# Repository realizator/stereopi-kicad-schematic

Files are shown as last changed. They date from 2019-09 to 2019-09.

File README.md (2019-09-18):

# StereoPi

This repo contains StereoPi schematics in KiCad. 
Originally, all schematics have been created in Altium, and now we're in the process of porting them to KiCad.

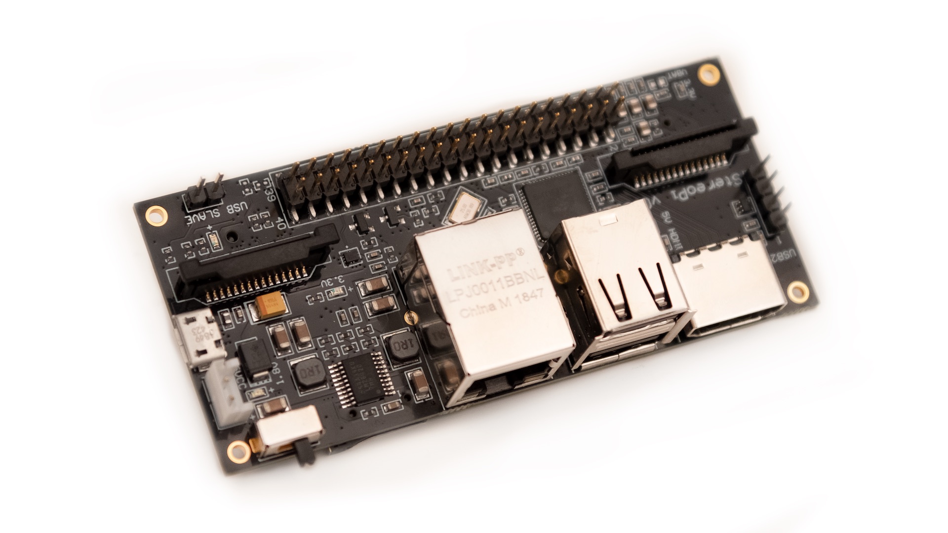
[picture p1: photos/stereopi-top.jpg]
StereoPi top photo


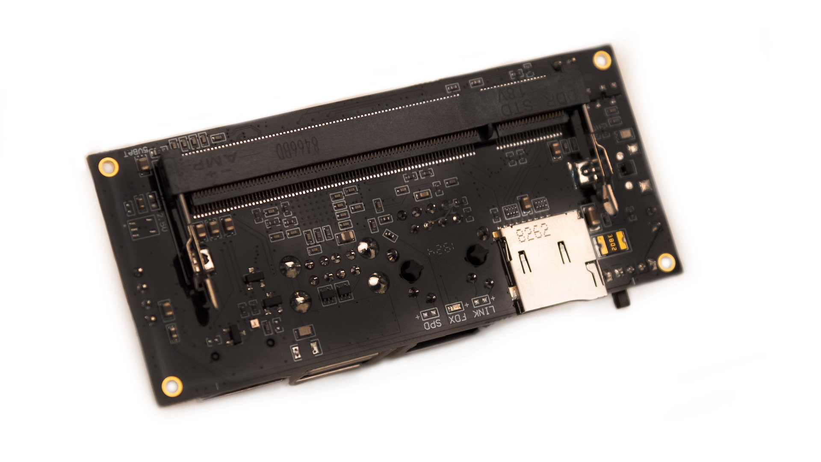
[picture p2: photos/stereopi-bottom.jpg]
StereoPi bottom photo


### Project site: 

http://stereopi.com

### Project Wiki:

https://wiki.stereopi.com

### Project forum:

https://forum.stereopi.com

**Special thanks to Twitter user @Knochi**

This man has achieved the gargantuan feat of drawing the first edition of our KiCad schematic from scratch!

Yes, this project is **Open Source**, and has been succesfully crowdfunded here:
https://www.crowdsupply.com/virt2real/stereopi

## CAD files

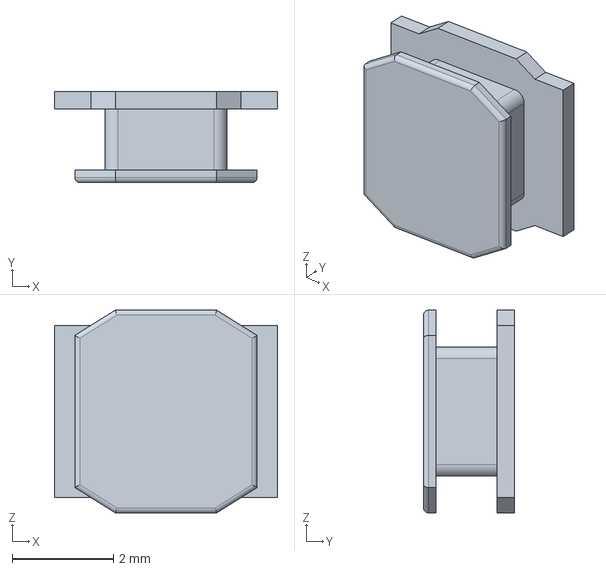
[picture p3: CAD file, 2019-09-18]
Datasheets/srn4018.stp
4.40 x 1.80 x 4.00 mm

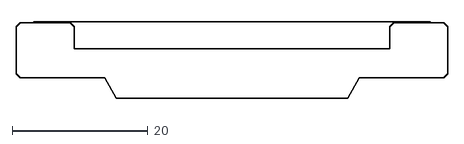
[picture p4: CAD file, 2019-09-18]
Datasheets/OutlineFPC.dxf
63.5 x 11.2

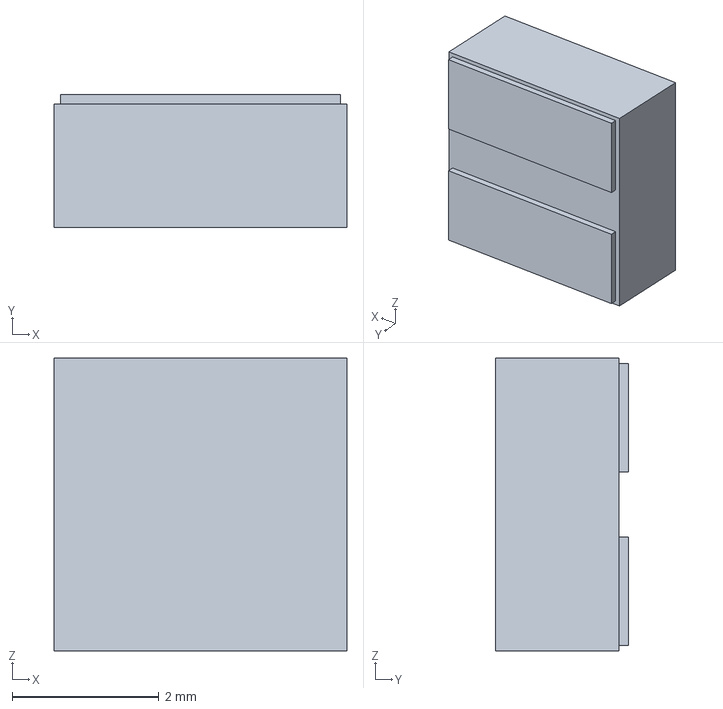
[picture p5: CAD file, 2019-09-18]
Datasheets/SRN4018TA.stp
3.99 x 1.80 x 3.99 mm

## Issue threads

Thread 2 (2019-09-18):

add Voltage requirements on C44 and C53

Knochi, 2019-09-18:
For separating capacitors between the grounds GND and GND_Sheild it will be great to mention their voltages on the schematic. This will help to understand, that this is a special capacitors, but not usual. I mean С44 and С53.

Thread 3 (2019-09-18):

Where are missing power pins on LAN9513

Knochi, 2019-09-18:
The question. LAN9513 chip has 5 power ports VDD33IO, but there is only pin19 on the schematics. Are there any other pins, or they are missed?

Knochi, 2019-09-18:
To make the schematic more clean those pins are hidden "behind" pin19. So all those pins get connected.

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

Closed 2019-09-18.

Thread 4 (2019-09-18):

Put conductor requirements on the schematics

Knochi, 2019-09-18:
**САМ – interface.**
Signals САМ0_D0, CAM0_D0, CAM0_C and CAM1_D0, CAM1_D0, CAM1_C has differential resistance 100 Ohm.
Mistmatch along the length in each diffpair 5mil (0.127mm).
Mistmatch along the length in each diffpair in interface САМ0 is 100mil.
Mistmatch along the length in each diffpair  in interfaceСАМ1 is 100mil.

**HDMI – interface**
Signals HDMI_D[2..0], HDMI_CLK has differential resistance of 100 Ohm.
Mistmatch along the length in each diffpair  is 5mil.
Data HDMI_D[2..0] equalized by length with respect to HDMI_CLK within 100mil.

**USB – interface**
USB-signals lines has  differential resistance 90 Ohm.
Mistmatch along the length in each diffpair is 5mil.
No need to equalize length of USB data between each other.

**Ethernet – interface LAN9513**
Tx and Rx signals differential resistance 100 Ohm.
Mistmatch along the length in each diffpair is 5mil.
No need to equalize length of Tx and Rx between each other.

Knochi, 2019-09-18:
Albeit the layout is already done, this maybe a good idea to help someone with their on layout version.
To find out how differential pair length matching is done in KiCAD see https://www.youtube.com/watch?v=chejn7dqpfQ

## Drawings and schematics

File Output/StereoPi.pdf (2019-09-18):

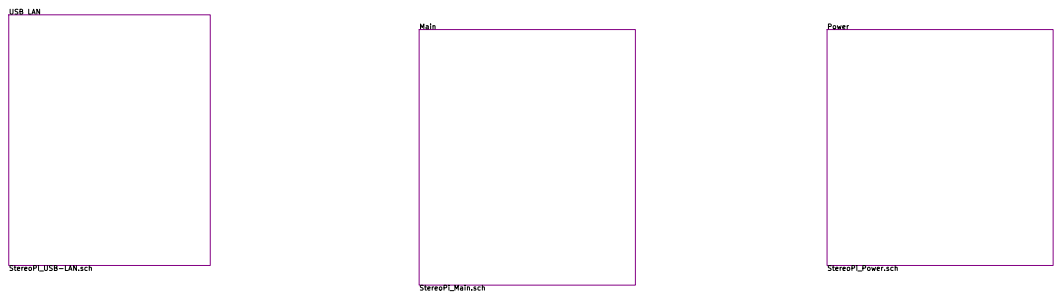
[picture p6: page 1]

Main StereoPi_Main.sch USB LAN

Id: 1/4 Title: File: StereoPi.sch Sheet: /

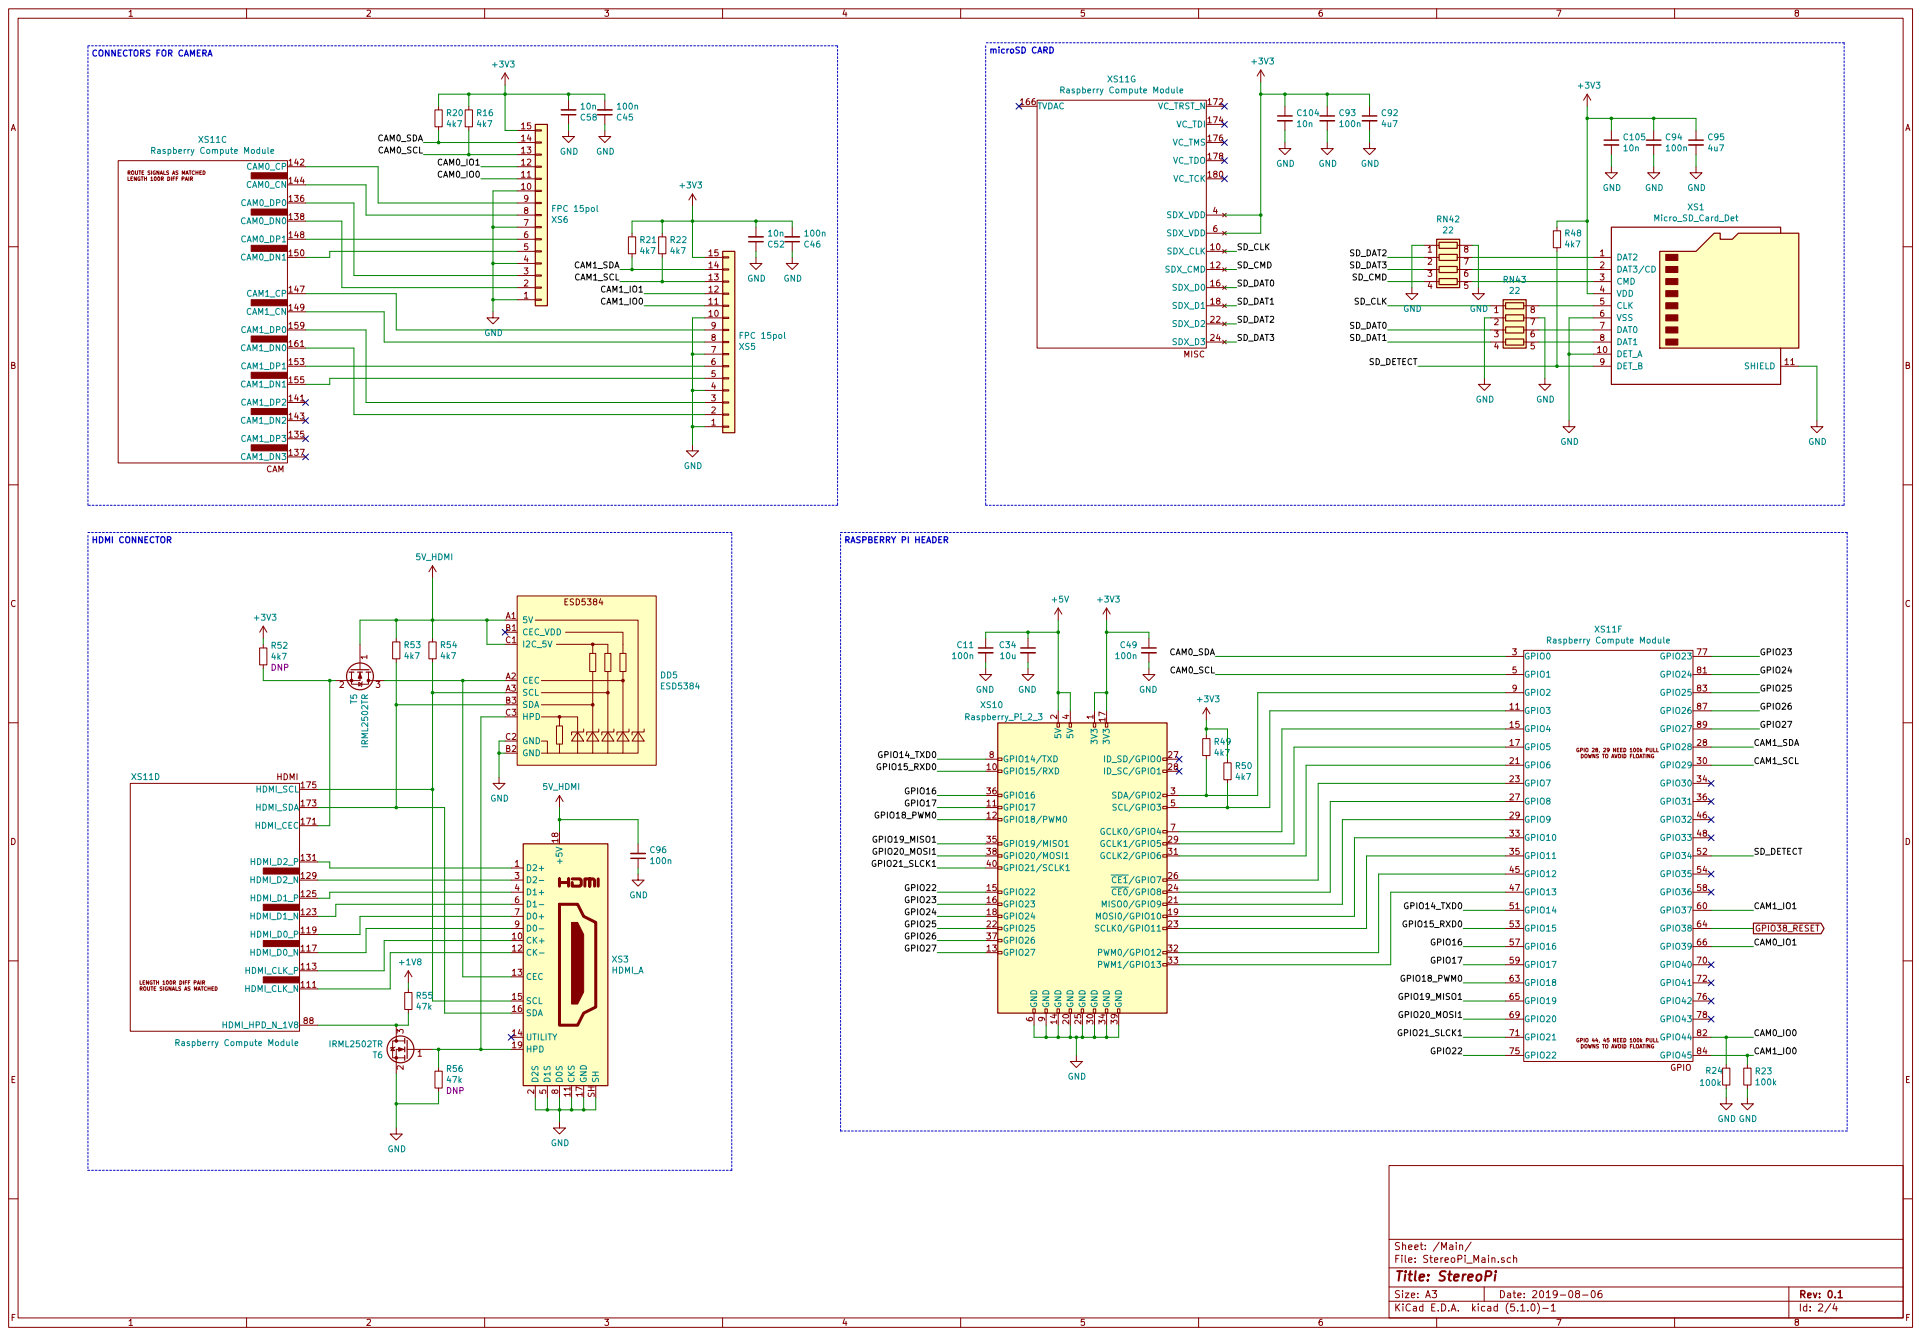
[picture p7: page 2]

89 XS11F Raspberry Compute Module CAM

9 XS10 Raspberry_Pi_2_3 D2+ 1 CK+ 10 CKS 11 CK- 12 CEC 13 UTILITY 14 SCL 15 SDA 16 GND 17 +5V 18 HPD 19 D2S

DOWNS TO AVOID FLOATING

File: StereoPi_Main.sch Sheet: /Main/
Id: 2/4 Title: StereoPi

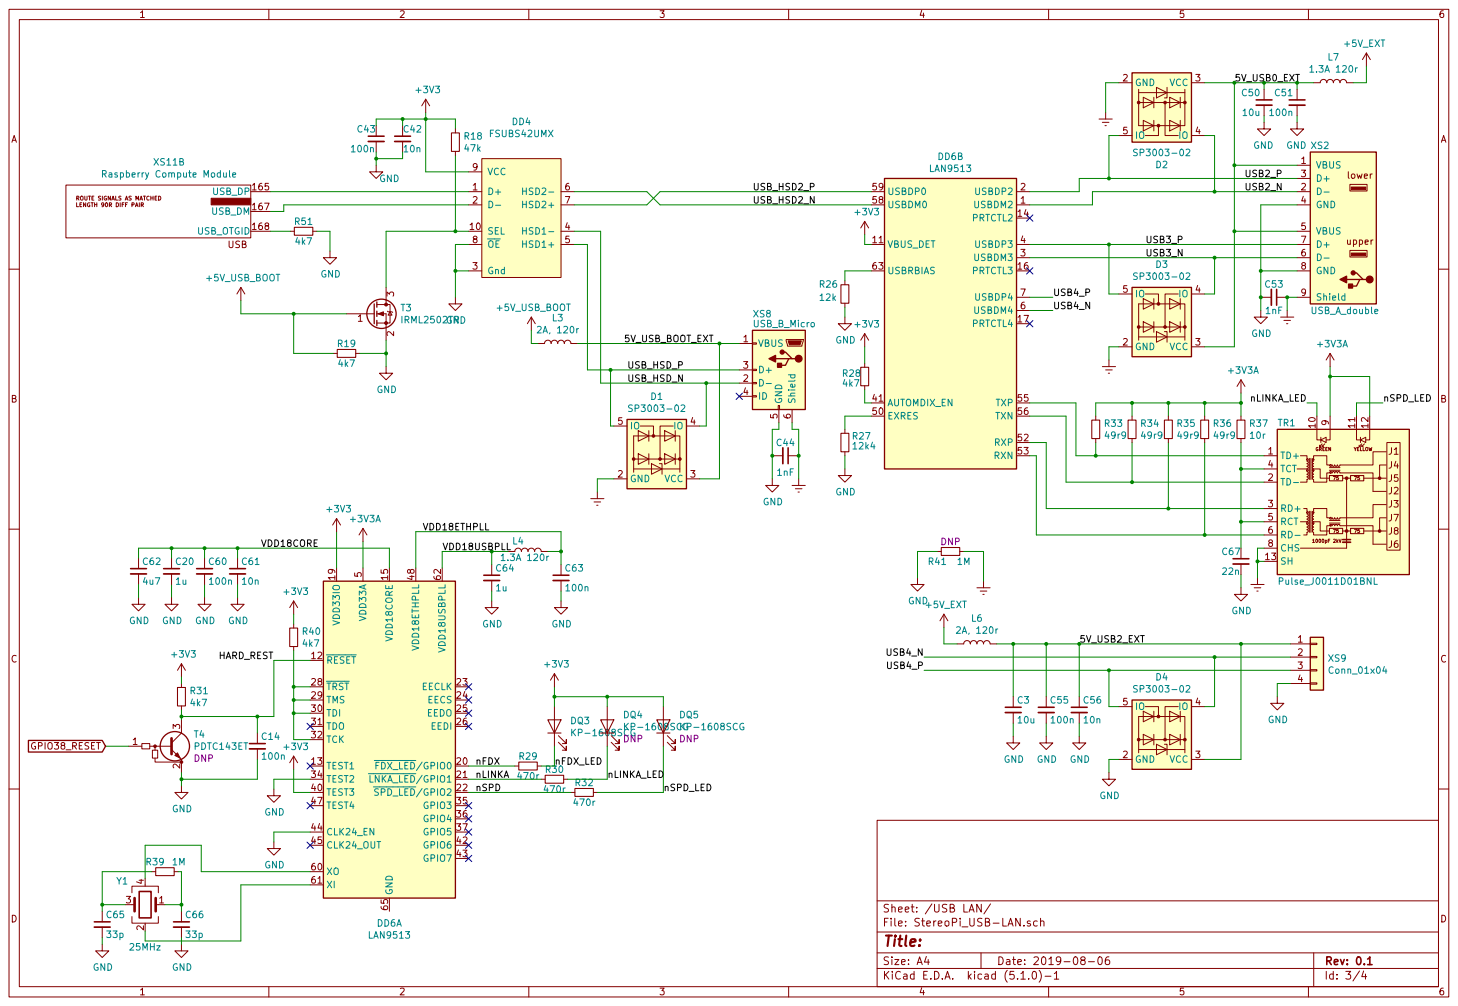
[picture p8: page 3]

VBUS 1 D- 2 D+ 3

USB_HSD_N

File: StereoPi_USB-LAN.sch Sheet: /USB LAN/
Id: 3/4 Title:

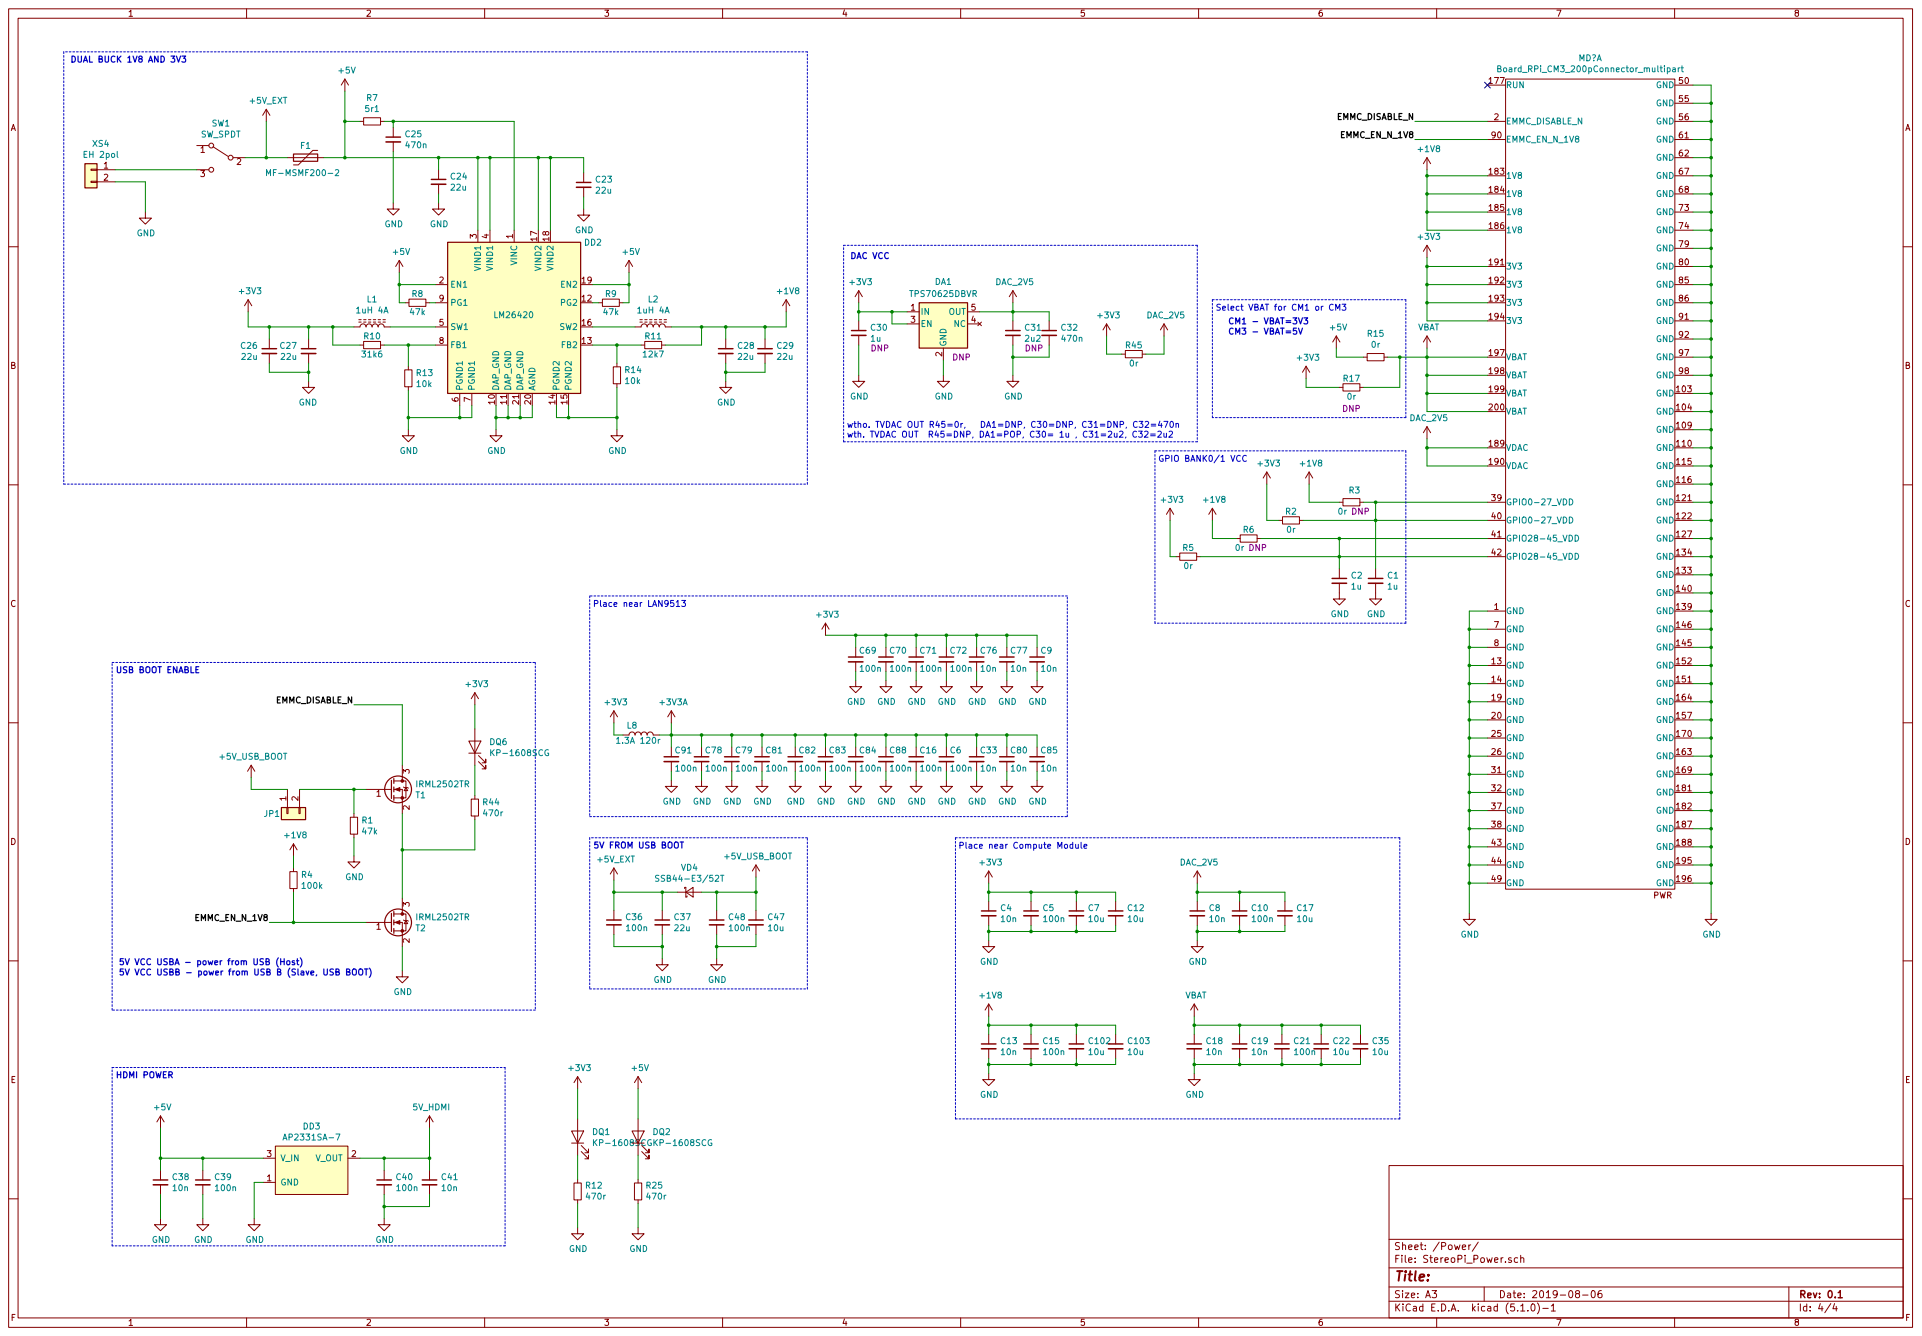
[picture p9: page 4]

10n GND GND GND GND GND GND GND

470r 5V VCC USBA - power from USB (Host)

5V VCC USBB - power from USB B (Slave, USB BOOT)

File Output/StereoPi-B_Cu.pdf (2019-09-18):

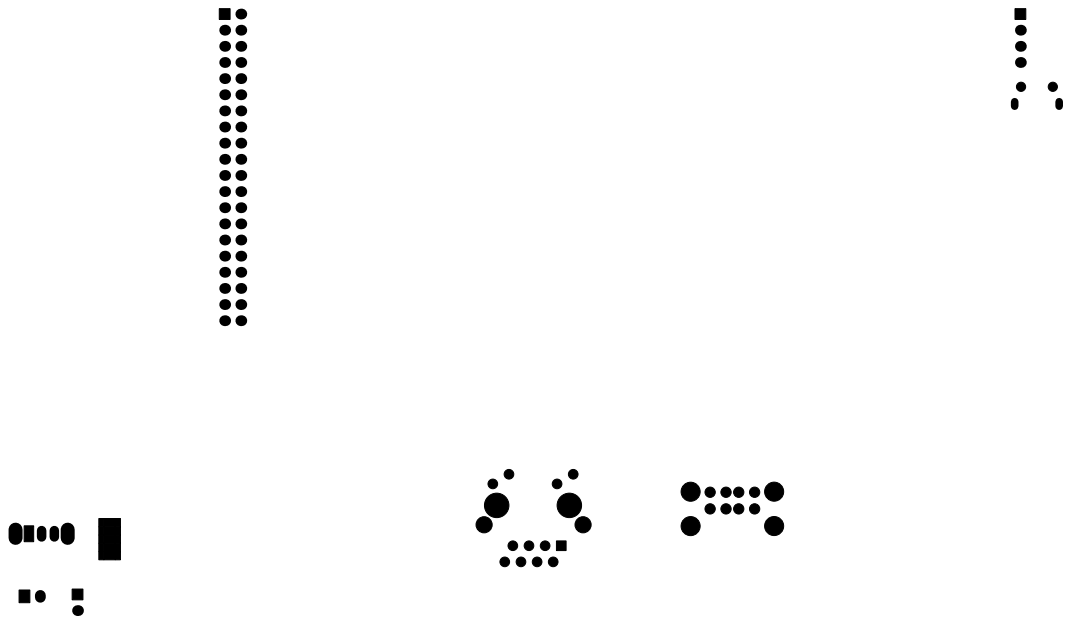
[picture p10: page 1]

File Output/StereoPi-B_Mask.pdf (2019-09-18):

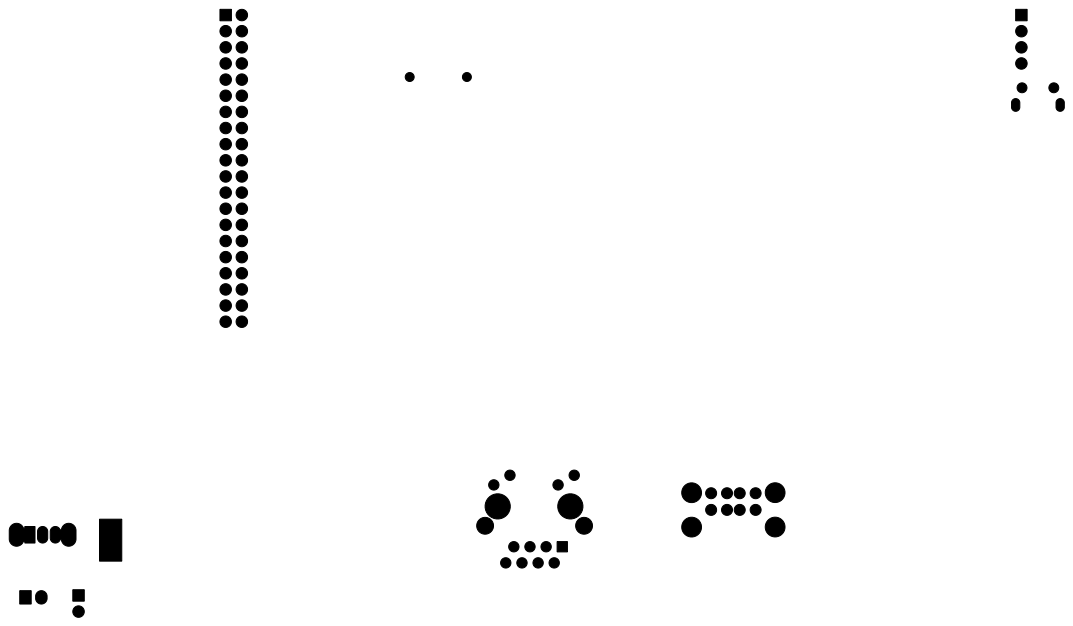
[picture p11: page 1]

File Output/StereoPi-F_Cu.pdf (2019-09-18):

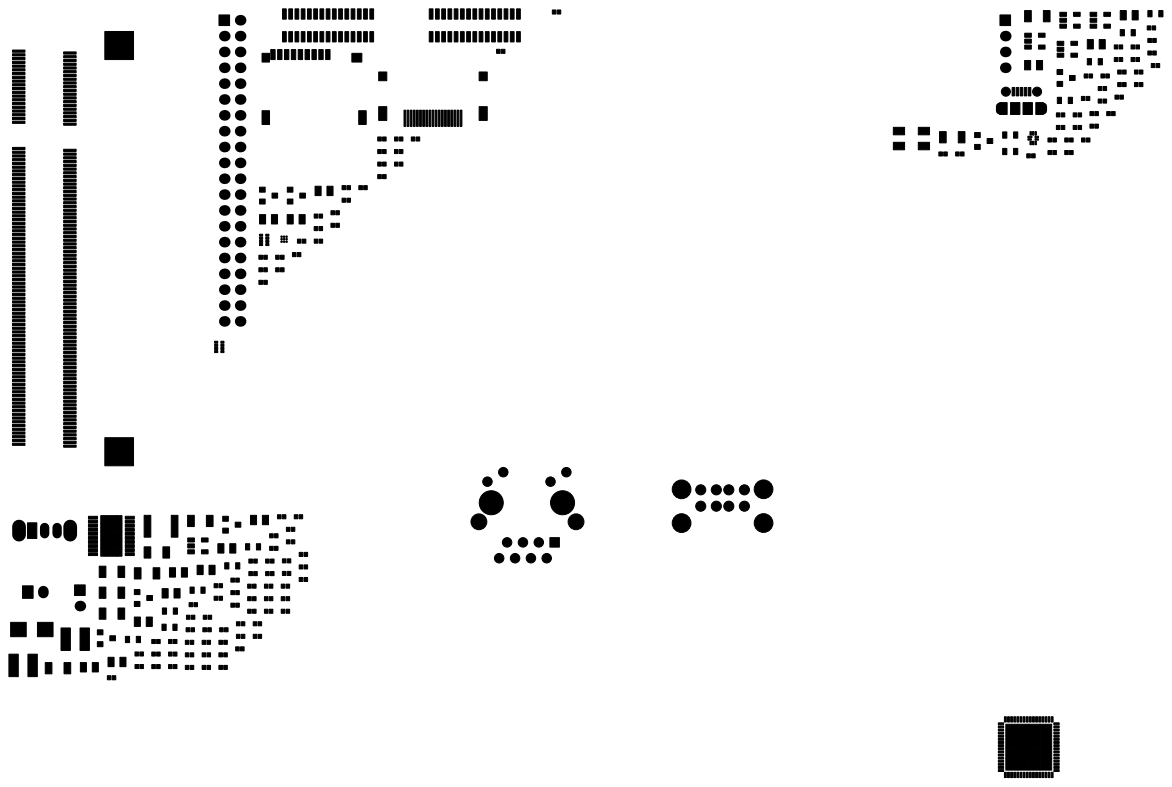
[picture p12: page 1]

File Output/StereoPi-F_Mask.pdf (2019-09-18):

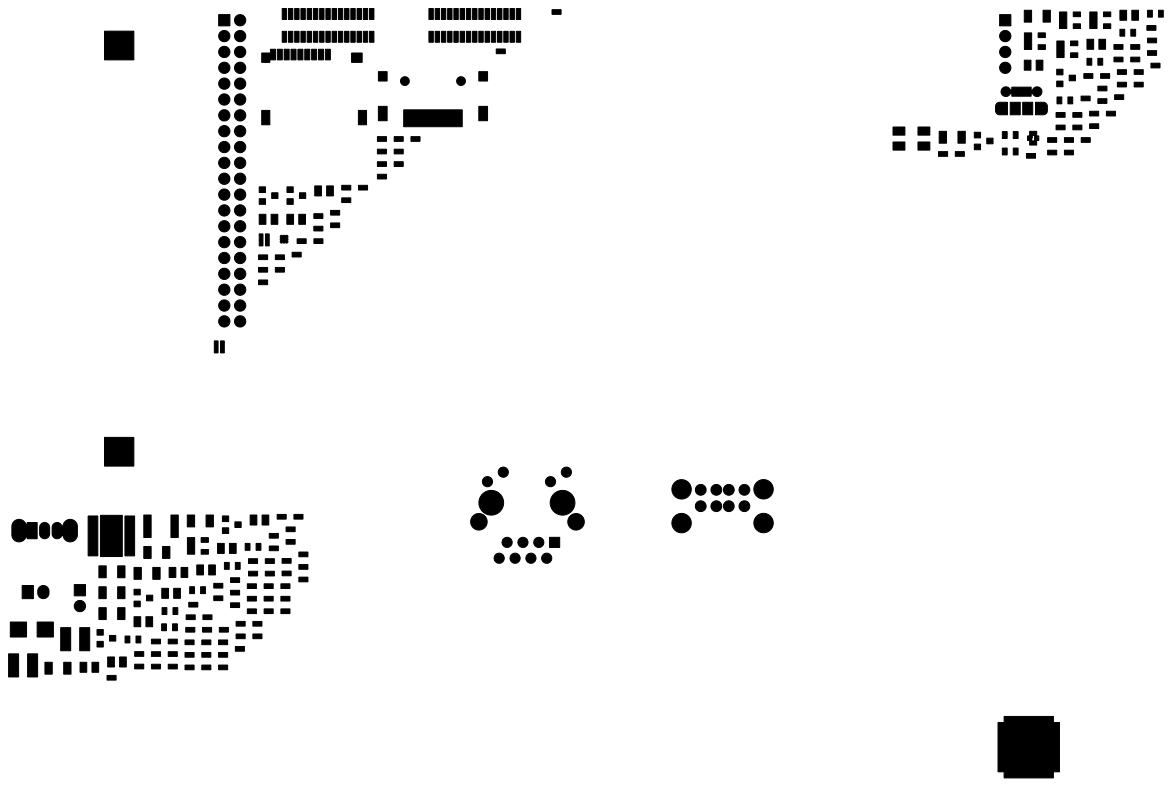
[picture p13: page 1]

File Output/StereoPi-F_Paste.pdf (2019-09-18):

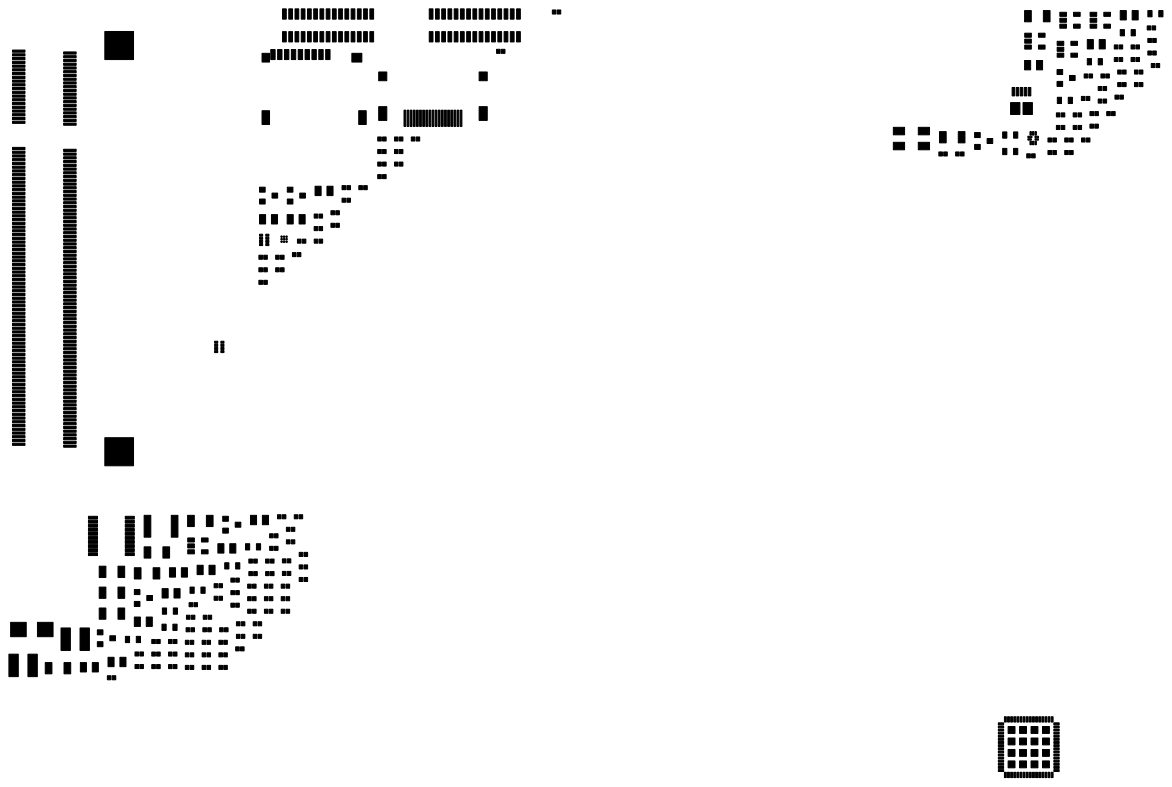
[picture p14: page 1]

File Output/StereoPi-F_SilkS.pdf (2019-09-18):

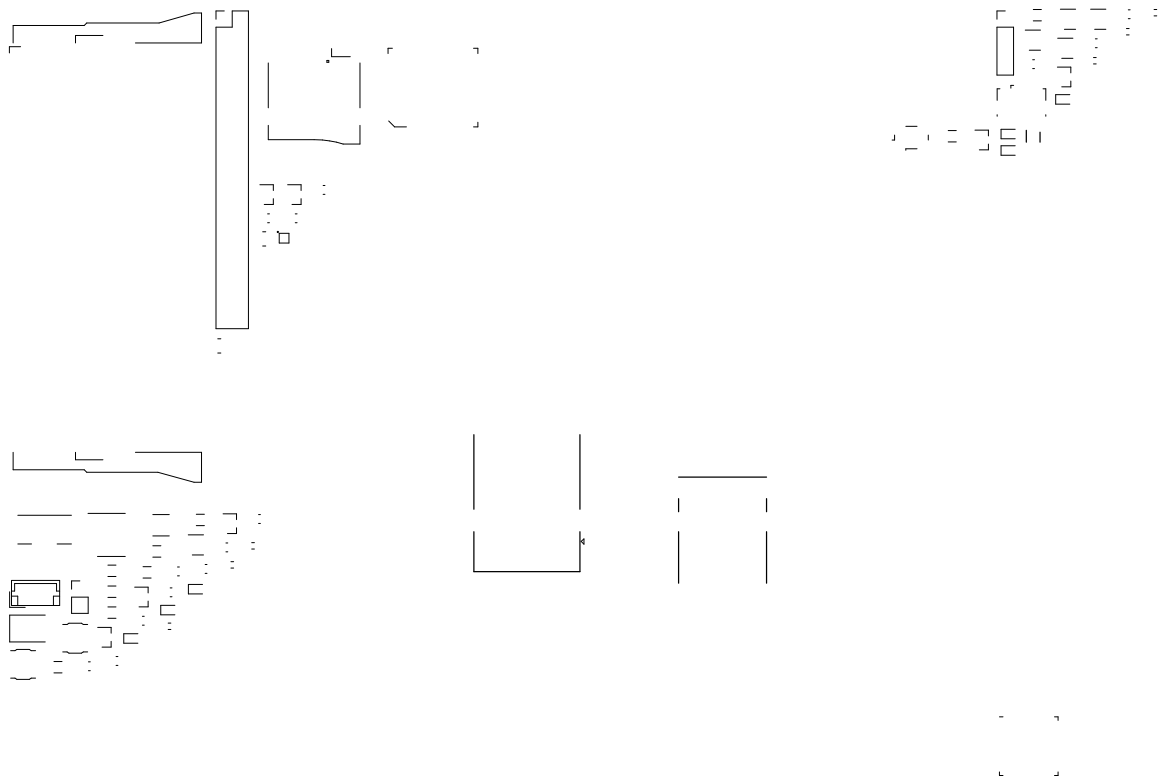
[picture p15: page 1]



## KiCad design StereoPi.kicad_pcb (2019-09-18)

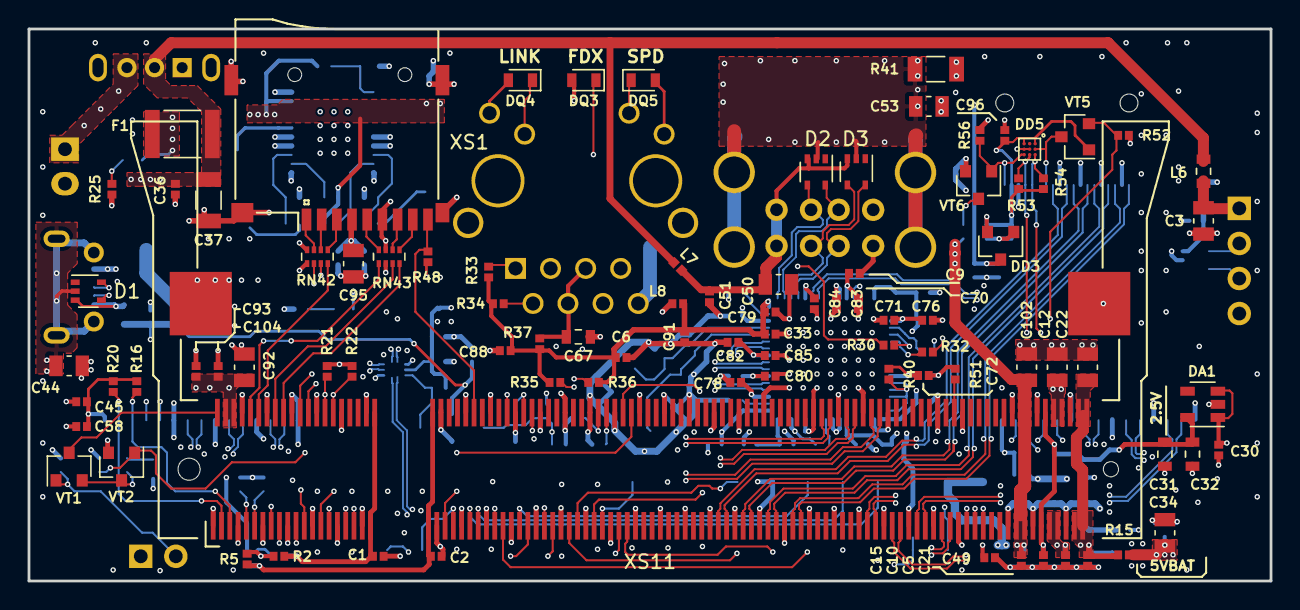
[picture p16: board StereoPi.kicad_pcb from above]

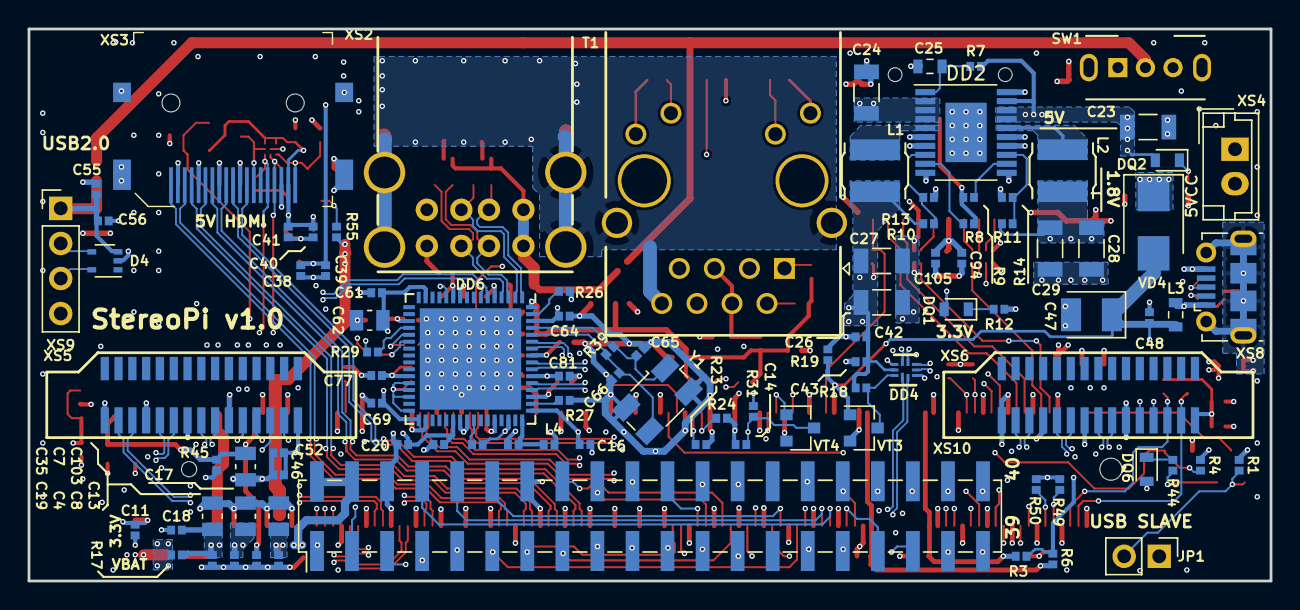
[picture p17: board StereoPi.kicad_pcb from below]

Board: 6 copper layers, 90.0 x 40.0 mm, 187 parts (98 on the bottom side), 141 nets.

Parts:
C1, C2, C20, C30, C64: 1u; C_0402_1005Metric
C3, C7, C12, C17, C22, C34, C35, C50, C102, C103: 10u; C_0805_2012Metric
C4, C8, C9, C13, C18, C19, C33, C38, C41, C42, C52, C56, C58, C61, C76, C77, C80, C85, C104, C105: 10n; C_0402_1005Metric
C5, C6, C10, C11, C14, C15, C16, C21, C36, C39, C40, C43, C45, C46, C48, C49, C51, C55, C60, C63, C69, C70, C71, C72, C78, C79, C81, C82, C83, C84, C88, C91, C93, C94, C96: 100n; C_0402_1005Metric
C23, C24, C26, C27, C28, C29, C37: 22u; C_1206_3216Metric
C25, C32: 470n; C_0603_1608Metric
C31: 2u2; C_0603_1608Metric
C44, C53: 1nF; C_0805_2012Metric
C47: 10u/10V; CP_EIA-3528-15_AVX-H
C62, C92, C95: 4u7; C_0805_2012Metric
C65, C66: 33p; C_0402_1005Metric
C67: 22n; C_0603_1608Metric
D1, D2, D3, D4: SP3003-02; SOT-353_SC-70-5
DA1: TPS70625; SOT-23-5
DD2: LM26420; HTSSOP-20-1EP_4.4x6.5mm_P0.65mm_ThermalPad_Ti
DD3: AP2331SA-7; SOT-23
DD4: FSUBS42UMX; UMLP-10_1.4x1.8x0.5mm_P0.4mm
DD5: ESD5384; WLCSP-9_1.14x1.14mm_P0.4mm
DD6: LAN9513; QFN-64-1EP_9x9mm_P0.5mm
DQ1, DQ2, DQ3, DQ4, DQ5, DQ6: KP-1608SCG; LED_0603_1608Metric
F1: MF-MSMF200-2; Fuse_1812_4532Metric
JP1: Conn_01x02; PinHeader_1x02_P2.54mm_Vertical
L1, L2: 1uH 4A; L_Bourns-SRN4018
L3, L6: 2A, 120r; L_0603_1608Metric
L4, L7, L8: 1.3A 120r; L_0402_1005Metric
R1, R8, R9, R18, R55, R56: 47k; R_0402_1005Metric
R2, R3, R5, R6, R15, R17, R45: 0r; R_0402_1005Metric
R4, R23, R24: 100k; R_0402_1005Metric
R7: 5r1; R_0402_1005Metric
R10: 31k6; R_0402_1005Metric
R11: 12k7; R_0402_1005Metric
R12, R25, R29, R30, R32, R44: 470r; R_0402_1005Metric
R13, R14: 10k; R_0402_1005Metric
R16, R19, R20, R21, R22, R28, R31, R40, R48, R49, R50, R51, R52, R53, R54: 4k7; R_0402_1005Metric
R26: 12k; R_0402_1005Metric
R27: 12k4; R_0402_1005Metric
R33, R34, R35, R36: 49r9; R_0402_1005Metric
R37: 10r; R_0402_1005Metric
R39: 1M; R_0402_1005Metric
R41: 1M; R_1206_3216Metric
RN42, RN43: 22; R_Array_Concave_4x0402
SW1: SW_SPDT; SK12D07VG3
T1: Pulse_J0011D01BNL; Conn_RJ45_Transformer_LEDs
VD4: SSB44; D_SMB
VT1, VT2, VT3, VT5, VT6: IRML2502TR; SOT-23
VT4: PDTC143ET; SOT-23
XS1: Micro_SD_Card_Det; Conn_uSDcard
XS2: USB_A_double; CON_USB-A_2-port
XS3: HDMI_A; HDMI_A_Female_2000-1-2-41-00-BK
XS4: EH 2pol; JST_EH_B02B-EH-A_1x02_P2.50mm_Vertical
XS5, XS6: FPC 15pol; FPC-15_VERTICAL_2
XS8: USB_B_Micro; USB_Micro-B_Molex-105017-0001
XS9: Conn_01x04; PinHeader_1x04_P2.54mm_Vertical
XS10: Raspberry_Pi_2_3; PinHeader_2x20_P2.54mm_Vertical_SMD
XS11: S0DIMM DDR2 Standard; Conn_TE-DDR2-SODIMM-0.6-200P-doublesided
Y1: 25MHz; Crystal_SMD_Abracon_ABM3B-4Pin_5.0x3.2mm

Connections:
1V8: C13.1, C15.1, C28.1, C29.1, C102.1, C103.1, L2.2, R3.2, R4.1, R6.2, R11.1, R55.1, XS11.183, XS11.184, XS11.185, XS11.186
3V3: C4.1, C5.1, C7.1, C9.1, C12.1, C26.1, C27.1, C30.1, C42.1, C43.1, C45.2, C46.2, C49.1, C52.2, C58.2, C69.1, C70.1, C71.1, C72.1, C76.1, C77.1, C92.1, C93.1, C94.1, C95.1, C104.1, C105.1, DA1.1, DA1.3, DD4.9, DD6.11, DD6.19, DD6.27, DD6.33, DD6.39, DD6.40, DD6.46, DQ1.2, DQ3.2, DQ4.2, DQ5.2, DQ6.2, L1.1, L8.1, R2.2, R5.2, R10.2, R16.1, R17.2, R18.1, R20.1, R21.1, R22.1, R28.1, R31.1, R40.1, R45.2, R48.2, R49.1, R50.1, R52.1, T1.9, T1.12, XS1.4, XS5.15, XS6.15, XS10.1, XS10.17, XS11.4, XS11.6, XS11.191, XS11.192, XS11.193, XS11.194
5VCC: C11.1, C23.1, C24.1, C34.1, C38.1, C39.1, DD2.2, DD2.3, DD2.4, DD2.17, DD2.18, DD2.19, DD3.3, DQ2.2, F1.1, R7.2, R8.2, R9.2, R15.2, XS10.2, XS10.4
5VCC_EXT: C36.1, C37.1, F1.2, L6.1, L7.1, SW1.2, VD4.1
5VCC_HDMI: C40.1, C41.1, C96.2, DD3.2, DD5.A1, DD5.C1, R53.1, R54.1, VT5.1, XS3.18
5V_EXT: SW1.3, XS4.1
+1V8_CORE: C20.1, C60.1, C61.1, C62.1, DD6.15, DD6.38
+1V8_ETH: C63.1, DD6.48, L4.2
+3V3A: C6.1, C16.1, C33.1, C78.1, C79.1, C80.1, C81.1, C82.1, C83.1, C84.1, C85.1, C88.1, C91.1, DD6.5, DD6.10, DD6.49, DD6.51, DD6.54, DD6.57, DD6.64, L8.2, R33.1, R34.1, R35.1, R36.1, R37.1
+5V_USB_BOOT: C47.1, C48.1, JP1.1, L3.1, R19.2, VD4.2, VT3.1
/Main/CAM0_IO0: R24.1, XS6.11, XS11.82
/Main/CAM0_IO1: XS6.12, XS11.66
/Main/CAM0_SCL: R16.2, XS6.13, XS11.5
/Main/CAM0_SDA: R20.2, XS6.14, XS11.3
/Main/CAM1_IO0: R23.1, XS5.11, XS11.84
/Main/CAM1_IO1: XS5.12, XS11.60
/Main/CAM1_SCL: R22.2, XS5.13, XS11.30
/Main/CAM1_SDA: R21.2, XS5.14, XS11.28
/Main/GPIO14_TXD0: XS10.8, XS11.51
/Main/GPIO15_RXD0: XS10.10, XS11.53
/Main/GPIO16: XS10.36, XS11.57
/Main/GPIO17: XS10.11, XS11.59
/Main/GPIO18_PWM0: XS10.12, XS11.63
/Main/GPIO19_MISO1: XS10.35, XS11.65
/Main/GPIO20_MOSI1: XS10.38, XS11.69
/Main/GPIO21_SLCK1: XS10.40, XS11.71
/Main/GPIO22: XS10.15, XS11.75
/Main/GPIO23: XS10.16, XS11.77
/Main/GPIO24: XS10.18, XS11.81
/Main/GPIO25: XS10.22, XS11.83
/Main/GPIO26: XS10.37, XS11.87
/Main/GPIO27: XS10.13, XS11.89
/Main/HDMI_CLK_N: XS3.12, XS11.111
/Main/HDMI_CLK_P: XS3.10, XS11.113
/Main/HDMI_D0_N: XS3.9, XS11.117
/Main/HDMI_D0_P: XS3.7, XS11.119
/Main/HDMI_D1_N: XS3.6, XS11.123
/Main/HDMI_D1_P: XS3.4, XS11.125
/Main/HDMI_D2_N: XS3.3, XS11.129
/Main/HDMI_D2_P: XS3.1, XS11.131
/Main/HDMI_SCL: DD5.A3, R54.2, XS3.15, XS11.175
/Main/HDMI_SDA: DD5.B3, R53.2, XS3.16, XS11.173
/Main/SD_CLK: RN43.1, XS11.10
/Main/SD_CMD: RN42.4, XS11.12
/Main/SD_DAT0: RN43.3, XS11.16
/Main/SD_DAT1: RN43.4, XS11.18
/Main/SD_DAT2: RN42.2, XS11.22
/Main/SD_DAT3: RN42.3, XS11.24
/Main/SD_DETECT: R48.1, XS1.9, XS11.52
/Power/1V8_SW: DD2.16, L2.1
/Power/3V3_SW: DD2.5, L1.2
/Power/EMMC_DISABLE_N: VT1.3, XS11.2
/Power/EMMC_EN_N_1V8: R4.2, VT2.1, XS11.90
/USB LAN/5V_USB0_EXT: C50.1, C51.1, D2.3, D3.3, L7.2, XS2.1, XS2.5
/USB LAN/5V_USB2_EXT: C3.1, C55.1, C56.1, D4.3, L6.2, XS9.1
/USB LAN/5V_USB_BOOT_EXT: D1.3, L3.2, XS8.1
/USB LAN/ETH_RX_N: DD6.53, R36.2, T1.6
/USB LAN/ETH_RX_P: DD6.52, R35.2, T1.3
/USB LAN/ETH_TX_N: DD6.56, R34.2, T1.2
/USB LAN/ETH_TX_P: DD6.55, R33.2, T1.1
/USB LAN/HARD_RESET: C14.1, DD6.12, R31.2, VT4.3
/USB LAN/USB2_N: D2.4, DD6.1, XS2.2
/USB LAN/USB2_P: D2.5, DD6.2, XS2.3
/USB LAN/USB3_N: D3.4, DD6.3, XS2.6
/USB LAN/USB3_P: D3.5, DD6.4, XS2.7
/USB LAN/USB4_N: D4.4, DD6.6, XS9.2
/USB LAN/USB4_P: D4.5, DD6.7, XS9.3
/USB LAN/USB_HSD2_N: DD4.6, DD6.58
/USB LAN/USB_HSD2_P: DD4.7, DD6.59
/USB LAN/USB_HSD_N: D1.4, DD4.4, XS8.2
/USB LAN/USB_HSD_P: D1.5, DD4.5, XS8.3
/USB LAN/VDD18USBPLL: C64.1, DD6.62, L4.1
/USB LAN/nFDX: DD6.20, R29.2
/USB LAN/nFDX_LED: DQ3.1, R29.1
/USB LAN/nLINKA: DD6.21, R30.2
/USB LAN/nLINKA_LED: DQ4.1, R30.1, T1.10
/USB LAN/nSPD: DD6.22, R32.2
/USB LAN/nSPD_LED: DQ5.1, R32.1, T1.11
DAC_2V5: C8.1, C10.1, C17.1, C31.1, C32.1, DA1.5, R45.1, XS11.189, XS11.190
GND: C1.2, C2.2, C3.2, C4.2, C5.2, C6.2, C7.2, C8.2, C9.2, C10.2, C11.2, C12.2, C13.2, C14.2, C15.2, C16.2, C17.2, C18.2, C19.2, C20.2, C21.2, C22.2, C23.2, C24.2, C25.2, C26.2, C27.2, C28.2, C29.2, C30.2, C31.2, C32.2, C33.2, C34.2, C35.2, C36.2, C37.2, C38.2, C39.2, C40.2, C41.2, C42.2, C43.2, C44.2, C45.1, C46.1, C47.2, C48.2, C49.2, C50.2, C51.2, C52.1, C53.2, C55.2, C56.2, C58.1, C60.2, C61.2, C62.2, C63.2, C64.2, C65.2, C66.2, C67.2, C69.2, C70.2, C71.2, C72.2, C76.2, C77.2, C78.2, C79.2, C80.2, C81.2, C82.2, C83.2, C84.2, C85.2, C88.2, C91.2, C92.2, C93.2, C94.2, C95.2, C96.1, C102.2, C103.2, C104.2, C105.2, D4.2, DA1.2, DD2.6, DD2.7, DD2.10, DD2.11, DD2.14, DD2.15, DD2.20, DD2.21, DD3.1, DD4.3, DD4.8, DD5.B2, DD5.C2, DD6.34, DD6.44, DD6.65, R1.2, R12.1, R13.2, R14.2, R19.1, R23.2, R24.2, R25.1, R26.2, R27.2, R41.2, R51.1, R56.2, RN42.1, RN42.8, RN43.2, RN43.7, VT2.2, VT3.2, VT4.2, VT6.2, XS1.6, XS1.10, XS2.4, XS2.8, XS3.2, XS3.5, XS3.8, XS3.11, XS3.17, XS3.SH, XS4.2, XS5.1, XS5.4, XS5.7, XS5.10, XS6.1, XS6.4, XS6.7, XS6.10, XS8.5, XS9.4, XS10.6, XS10.9, XS10.14, XS10.20, XS10.25, XS10.30, XS10.34, XS10.39, XS11.1, XS11.7, XS11.8, XS11.13, XS11.14, XS11.19, XS11.20, XS11.25, XS11.26, XS11.31, XS11.32, XS11.37, XS11.38, XS11.43, XS11.44, XS11.49, XS11.50, XS11.55, XS11.56, XS11.61, XS11.62, XS11.67, XS11.68, XS11.73, XS11.74, XS11.79, XS11.80, XS11.85, XS11.86, XS11.91, XS11.92, XS11.97, XS11.98, XS11.103, XS11.104, XS11.109, XS11.110, XS11.115, XS11.116, XS11.121, XS11.122, XS11.127, XS11.133, XS11.134, XS11.139, XS11.140, XS11.145, XS11.146, XS11.151, XS11.152, XS11.157, XS11.163, XS11.164, XS11.169, XS11.170, XS11.181, XS11.182, XS11.187, XS11.188, XS11.195, XS11.196, Y1.2, Y1.4
GPIO38_RESET: VT4.1, XS11.64
unnamed: C1.1, R2.1, R3.1, XS11.39, XS11.40
unnamed: C2.1, R5.1, R6.1, XS11.41, XS11.42
unnamed: C25.1, DD2.1, R7.1
unnamed: C65.1, DD6.61, R39.1, Y1.1
unnamed: C66.1, DD6.60, R39.2, Y1.3
unnamed: C67.1, R37.2, T1.4, T1.5
unnamed: DD2.8, R10.1, R13.1
unnamed: DD2.9, R8.1
unnamed: DD2.12, R9.1
unnamed: DD2.13, R11.2, R14.1
unnamed: DD4.1, XS11.165
unnamed: DD4.2, XS11.167
unnamed: DD4.10, R18.2, VT3.3
unnamed: DD5.A2, VT5.3, XS3.13
unnamed: DD5.C3, R56.1, VT6.1, XS3.19
unnamed: DD6.28, DD6.29, DD6.30, DD6.32, R40.2
unnamed: DD6.41, R28.2
unnamed: DD6.50, R27.1
unnamed: DD6.63, R26.1
unnamed: DQ1.1, R12.2
unnamed: DQ2.1, R25.2
unnamed: DQ6.1, R44.1
unnamed: JP1.2, R1.1, VT1.1
unnamed: R44.2, VT1.2, VT2.3
unnamed: R49.2, XS10.3, XS11.9
unnamed: R50.2, XS10.5, XS11.11
unnamed: R51.2, XS11.168
unnamed: R52.2, VT5.2, XS11.171
unnamed: R55.2, VT6.3, XS11.88
unnamed: RN42.5, XS1.3
unnamed: RN42.6, XS1.2
unnamed: RN42.7, XS1.1
unnamed: RN43.5, XS1.8
unnamed: RN43.6, XS1.7
unnamed: RN43.8, XS1.5
unnamed: XS10.7, XS11.15
unnamed: XS10.19, XS11.33
unnamed: XS10.21, XS11.29
unnamed: XS10.23, XS11.35
unnamed: XS10.24, XS11.27
unnamed: XS10.26, XS11.23
unnamed: XS10.29, XS11.17
unnamed: XS10.31, XS11.21
unnamed: XS10.32, XS11.45
unnamed: XS10.33, XS11.47
unnamed: XS6.3, XS11.136
unnamed: XS6.2, XS11.138
unnamed: XS6.9, XS11.142
unnamed: XS6.8, XS11.144
unnamed: XS5.9, XS11.147
unnamed: XS6.6, XS11.148
unnamed: XS5.8, XS11.149
unnamed: XS6.5, XS11.150
unnamed: XS5.6, XS11.153
unnamed: XS5.5, XS11.155
unnamed: XS5.3, XS11.159
unnamed: XS5.2, XS11.161
SHELF1_GND: C44.1, D1.2, XS8.6
SHELF_GND: C53.1, D2.2, D3.2, R41.1, T1.8, T1.13, XS2.9
VBAT: C18.1, C19.1, C21.1, C22.1, C35.1, R15.1, R17.1, XS11.197, XS11.198, XS11.199, XS11.200

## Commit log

2019-09-18 Innitial commit
    [OutlineFPC.dxf, SRN4018TA.stp, StereoPi.kicad_pcb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]
2019-09-19 added Voltages to Caps C44 and C53 fixed labels (bold to regular)
    [StereoPi.sch, StereoPi_Main.sch, StereoPi_Power.sch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]
2019-09-19 added .gitignore
    [OutlineFPC.dxf, SRN4018TA.stp, StereoPi.kicad_pcb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]
